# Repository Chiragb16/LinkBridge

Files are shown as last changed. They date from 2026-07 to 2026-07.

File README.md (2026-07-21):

# LinkBridge

### 10 Gbps Ethernet RJ45 Coupler Board

LinkBridge is a compact high-speed Ethernet coupler board designed to connect two shielded RJ45 connectors while preserving signal integrity for 10 Gbps communication. The board was designed in KiCad with controlled impedance routing, making it suitable for high-speed differential signals.

The primary goal of this project was to practice high-speed PCB layout techniques such as differential pair routing, impedance control, and connector placement while producing a manufacturing-ready design.

---

## Features

- Supports 10 Gbps Ethernet
- Dual Shielded RJ45 Connectors
- 102.4 Ω Differential Pair Routing
- Controlled Impedance PCB Layout
- Compact Board Design
- Manufacturing Ready
- Designed in KiCad

---
---

## Differential Pair Calculations

To achieve reliable **10 Gbps Ethernet communication**, the differential pair dimensions were calculated using **Saturn PCB Toolkit**.

The final routing parameters used were:

- Differential Impedance: **102.4 Ω**
- Trace Width: **0.105 mm**
- Trace Spacing: **0.150 mm**
- Copper Thickness: **35 μm**
- FR-4 Standard Stackup

These values were selected to closely match the target impedance required for high-speed Ethernet differential signaling.

<p align="center">
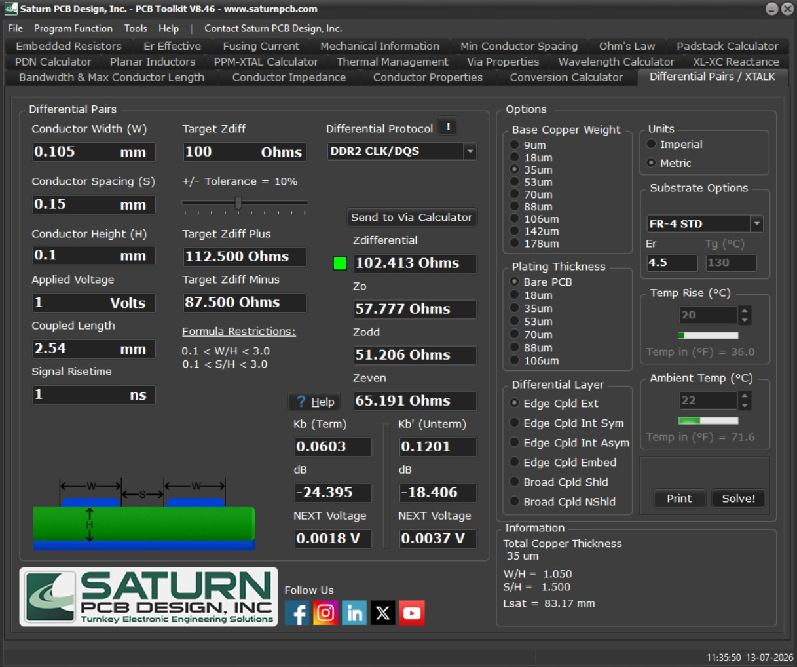
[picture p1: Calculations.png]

</p>

---

## PCB Preview

<p align="center">
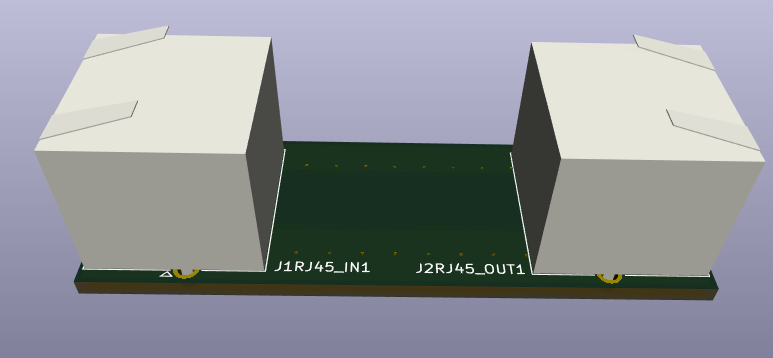
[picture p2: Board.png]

</p>

---

## Design Highlights

This board focuses on maintaining signal quality between two RJ45 connectors.

Some of the PCB design considerations include:

- 102.4 Ω differential impedance routing
- Length-matched differential pairs
- Symmetric connector placement
- Continuous ground reference
- Short and direct signal paths
- Manufacturing-friendly PCB layout

---

## Specifications

- Interface: RJ45
- Ethernet Speed: Up to 10 Gbps
- Differential Impedance: 102.4 Ω
- PCB Tool: KiCad
- PCB Type: High-Speed Interconnect Board

---

## Files Included

- KiCad Project
- PCB Layout
- Schematic
- Gerber Files
- Drill Files
- Technical Report

---

## Tools Used

- KiCad
- Git
- GitHub

---

## Project Status

- Schematic Completed
- PCB Layout Completed
- High-Speed Routing Completed
- Gerber Files Generated
- Technical Report Included
- Ready for Fabrication

---

This project was created as part of my PCB design practice to better understand high-speed Ethernet routing, impedance-controlled PCB design, and preparing hardware for manufacturing.

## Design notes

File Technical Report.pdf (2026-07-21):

## High-Speed Ethernet Differential Pair PCB Design

Candidate: Chirag Bhalla
Software: KiCad 10
Board Type: 4-Layer FR4 PCB

## Track Geometry

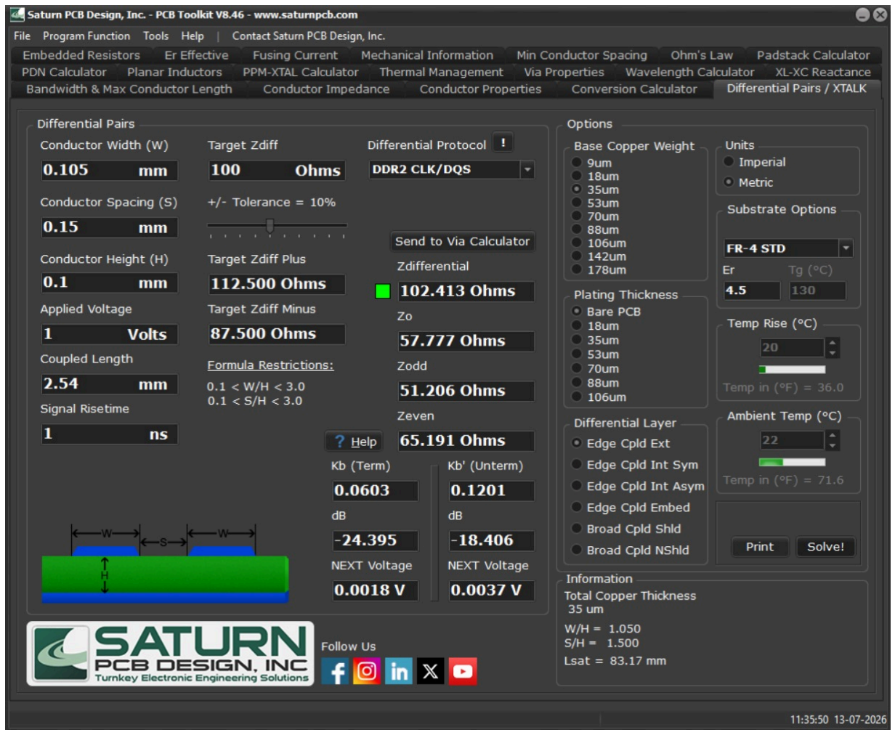
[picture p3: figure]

A 4-layer FR-4 stackup was selected with a 0.10 mm prepreg thickness between the top signal layer and the ground reference plane. Using Saturn PCB Toolkit, the differential pair geometry was calculated as 0.105 mm trace width with 0.15 mm spacing, resulting in a calculated differential impedance of 102.4 Ω, which is within acceptable tolerance of the 100 Ω target.

Trace Width | 0.105 mm
Differential Gap | 0.15 mm
Copper Thickness | 35 µm (1 oz)
Board Thickness | 1.6 mm
Dielectric Constant (εr) | 4.5
Calculated Differential Impedance | 102.413Ω

## High-Speed Routing

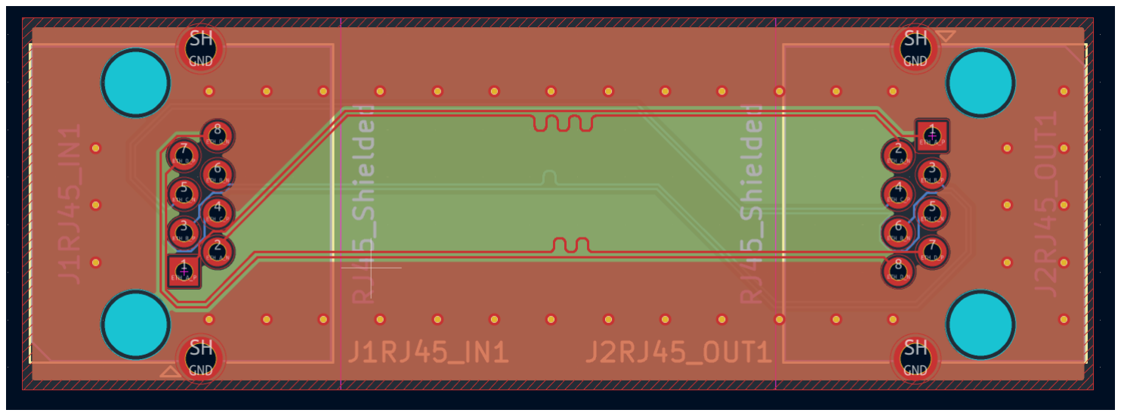
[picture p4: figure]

The Ethernet signals were routed as controlled differential pairs while maintaining constant trace width and spacing throughout the routing path.

To preserve signal integrity, the following routing practices were followed:

- Maintained consistent differential pair spacing.
- Used 45° bends to minimize impedance discontinuities.
- Minimized unnecessary layer transitions. The through-hole RJ45 connector pads were used where required to transition between the top and bottom routing layers without adding extra signal vias.
- Keep routing symmetrical between both connectors.
- Routed each pair together to maintain coupling.

## Length Matching

To minimize intra-pair skew, the lengths of the positive and negative traces were matched using KiCad's Differential Pair Tune Skew tool. . This ensures that both signals in each differential pair arrive at the destination at nearly the same time.

## Crosstalk Reduction

To improve signal integrity and reduce crosstalk between adjacent pairs, the following measures were implemented:

- Adequate spacing was maintained between neighbouring differential pairs.
- Continuous ground reference planes were provided on both inner layers.
- Ground stitching vias were added throughout the PCB to improve the connection between ground planes and provide a low-impedance return path.
- GND copper pours were added on both the top and bottom layers, while continuous solid ground planes were maintained on the two inner layers to provide a stable return path and improve shielding. .

These routing techniques help maintain controlled impedance while reducing noise and electromagnetic interference.

## Mechanical Design

The PCB was designed as a compact Ethernet interconnect board with two shielded RJ45 connectors placed at opposite ends. This connector arrangement enables clean and symmetrical differential pair routing. while keeping the trace lengths short and maintaining a clean, symmetrical layout. The final board dimensions are 56.145 mm × 19.560 mm, providing sufficient clearance for the connectors and routing without increasing the overall board size unnecessarily.

Since this design is intended as a passive Ethernet interconnect/evaluation board, dedicated mounting holes were not included. For a production design or enclosure-mounted application, mounting holes can be added based on the mechanical requirements of the final product.

## Manufacturing Strategy

The PCB is designed using a standard 4-layer FR4 stackup with 1 oz copper on all copper layers.

F.Cu | Differential pair routing + GND copper pour
In1.Cu | Solid GND Plane
In2.Cu | Solid GND Plane

B.Cu | Differential pair routing + GND copper pour

The dedicated inner ground planes provide a stable reference for the high-speed Ethernet signals, while the top and bottom copper pours improve shielding and ground continuity.

Ground stitching vias were added across the board to connect all ground planes together, helping reduce EMI and improve return current paths.

The recommended fabrication specifications are:

Parameter | Specification
Material | FR4
Layers | 4
Board Thickness | 1.6 mm
Copper Weight | 1 oz
Surface Finish | ENIG, 1 µin Gold Thickness

Before generating the manufacturing files, the following verification steps were completed:

- Design Rule Check (DRC)
- Copper zone refill
- Differential impedance verification using Saturn PCB Toolkit.
- Gerber inspection using KiCad Gerber Viewer

The final manufacturing package includes:

Gerber Files

- Gerber Files
- NC Drill Files
- Board Outline
- IPC-2581 (optional)
- Pick-and-Place Files (optional)
- Bill of Materials (optional)

All differential pairs were tuned to maintain minimal intra-pair skew. The final length differences were kept within KiCad's tuning tolerance, ensuring nearly simultaneous signal arrival for each pair.

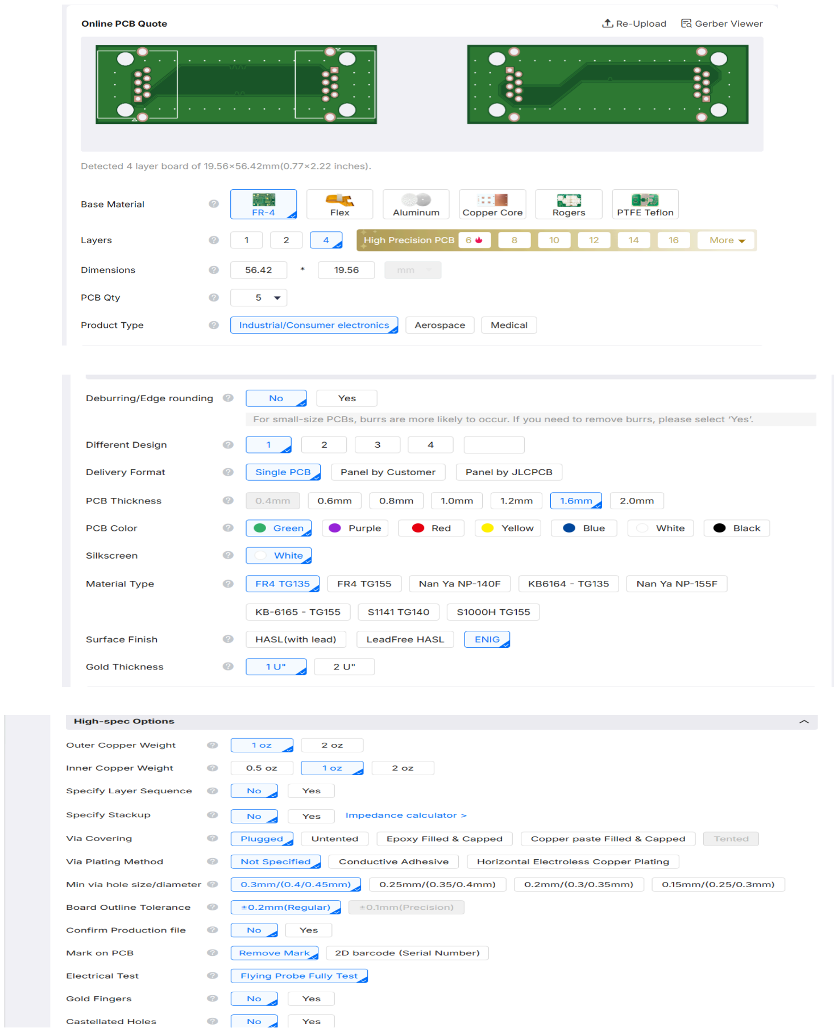
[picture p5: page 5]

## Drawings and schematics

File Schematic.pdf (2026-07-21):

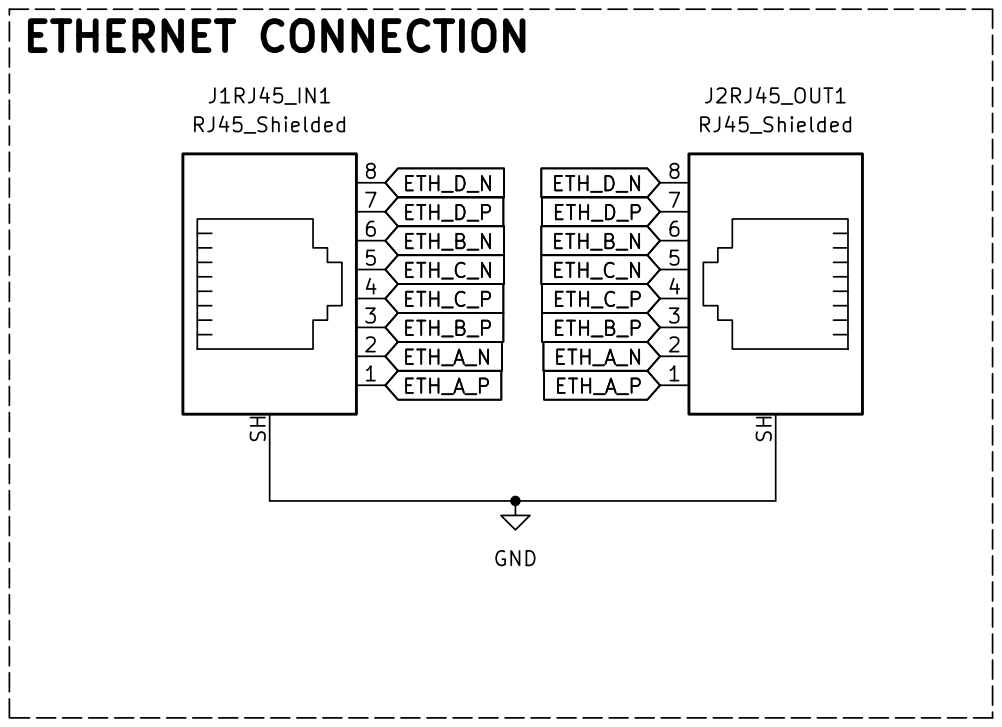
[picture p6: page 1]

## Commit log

2026-07-21 Add README for LinkBridge Ethernet Coupler Board
    Added detailed project information for the LinkBridge Ethernet coupler board, including features, specifications, and design highlights.
2026-07-21 Organize Gerber files into dedicated folder
    [Assignment-B_Cu.gbr, Assignment-B_Mask.gbr, Assignment-B_Paste.gbr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]
